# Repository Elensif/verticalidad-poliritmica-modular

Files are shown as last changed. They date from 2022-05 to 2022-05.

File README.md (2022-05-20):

# verticalidad-poliritmica-modular
Documentación del proyecto
Este proyecto corresponde a un trabajo perteneciente al segundo módulo del Taller de interacción, en dónde a partir de un trabajo previo de observación se diseño un tótem de 2mts. de altura con el cual una persona pueda interactuar. Los archivos de las siguientes carpetas corresponden a las piezas necesarias para armar el proyecto "Verticalidad polirítmica modular", dentro de ellas se podrán encontrar los documentos necesarios, descargables y editables para crear desde 0 el tótem.

Los autores de este proyecto son Nicolás Dragas, Daniela Sifaqui y Alejandra Witto, alumnos pertenecientes al Taller de interacción 2022 de la e[ad].
El registro del proyecto de inicio a fin se puede encontrar en el siguiente enlace: https://wiki.ead.pucv.cl/Verticalidad_polir%C3%ADtmica_modular

imagen

Dentro del repositorio existen 3 carpetas: cam, cad e ino. Dentro de la carpeta "cam" se encuentran los archivos de dibujo en formato "dwg" para descargar y editar, dentro de la carpeta "cad" se encuentran los modelos tridimensionales y en la carpeta "ino" se encuentra el código utilizado en arduino.

Los programas utilizados para realizar los archivos fueron: para los archivos DWG se utilizó autocad, para los modelos 3D se utilizó Iventor. Para cortar las piezas los archivos DWG se exportaron a .dxf y se cortarón en una láser. Para el registro gráfico se utilizaron render, inventor y cámaras de celular.

<br />Esta obra está bajo una <a rel="license" href="http://creativecommons.org/licenses/by-nc-sa/4.0/">Licencia Creative Commons Atribución-NoComercial-CompartirIgual 4.0 Internacional</a>.

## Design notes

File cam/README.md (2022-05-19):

Los siguientes archivos corresponden a todos los dibujos realizados en autocad para ser cortados en láser.

Los archivos: Piezas cajones gesto.dwg y Piezas cajones.dwg, corresponden a las piezas móviles del módulo. Para armar cada módulo se utilizó papel opalina blanco a de gramaje 200. Cada cajón cuenta con 1 pieza rectangular larga y dos pequeñas que van pegados a los costados. Cada pieza tiene viñetas las que se pegan entre si para tener bordes limpios en los cuerpos.
Los archivos ya se encuentran divididos en dos capas, una de corte y otra de grabado para realizar los plisados en el papel. Los parámetros utilizados para estos archivos fueron: 

Plisado (capa blanca)= Speed (mm/s): 500, sin repeticiones, Min Power(%) 15, Max Power(%) 15.

Corte (capa azul)= Speed (mm/s) 80, sin repeticiones, Min Power(%) 20, Max Power(%) 20.

Los archivos "Pieza separación interior.dwg", "Piezas interiores de cajones.dwg", "Piezas mecanismo carrito" corresponden a piezas que serán cortadas en MDF de 3mm de espesor. Los parámetros utilizados para estos archivos fueron:

Speed (mm/s) 30, sin repeticiones, Min Power(%) 70, Max Power(%) 70.

Los archivos "Dientes para cremallera.dwg" y "Engranaje presión para potenciometro.dwg", corresponden a las piezas que permiten el movimiento del potenciómerto del mecanismo eléctrico para hacer funcionar el sistema del tótem. 
Dentro del archivo "Dientes para cremallera.dwg" se encuentra un gran engranaje, para crear la cremallera según la extensión que se necesite se debe tomar un diente del engranaje e ir colocándolo uno al lado del otro hasta llegar a la longitud deseada, en el proyecto actual se hizo una pieza de 11cm x 2cm x 5mm, en donde a lo largo de los 11 centímetros va la cremallera.

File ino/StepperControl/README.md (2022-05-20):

El código que se encuentra en esta carpeta corresponde a uno utilizado en una placa arduino, para controlar la dirección y giro de un motor stepper con un potenciómetro.

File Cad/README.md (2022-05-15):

Los archivos que se encuentran de esta carpeta corresponden a los modelos 3D del tótem. Estos se realizaron con Inventor y se encuentran dibujados en escala 1:1.
Dentro de cada uno se puede ver el ensamblaje del proyecto, desde su estructura interna a externa.

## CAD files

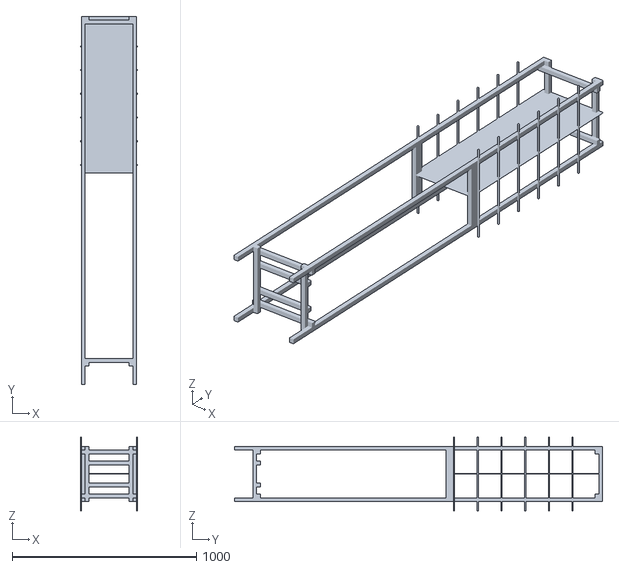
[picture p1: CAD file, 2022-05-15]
Cad/Esqueleto tótem.obj
312.0 x 2000.0 x 400.0

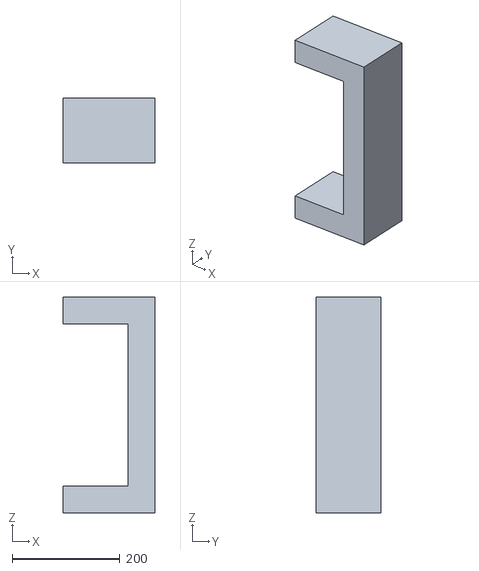
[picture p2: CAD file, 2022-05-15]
Cad/Cajón totem.obj
170.0 x 120.0 x 400.0

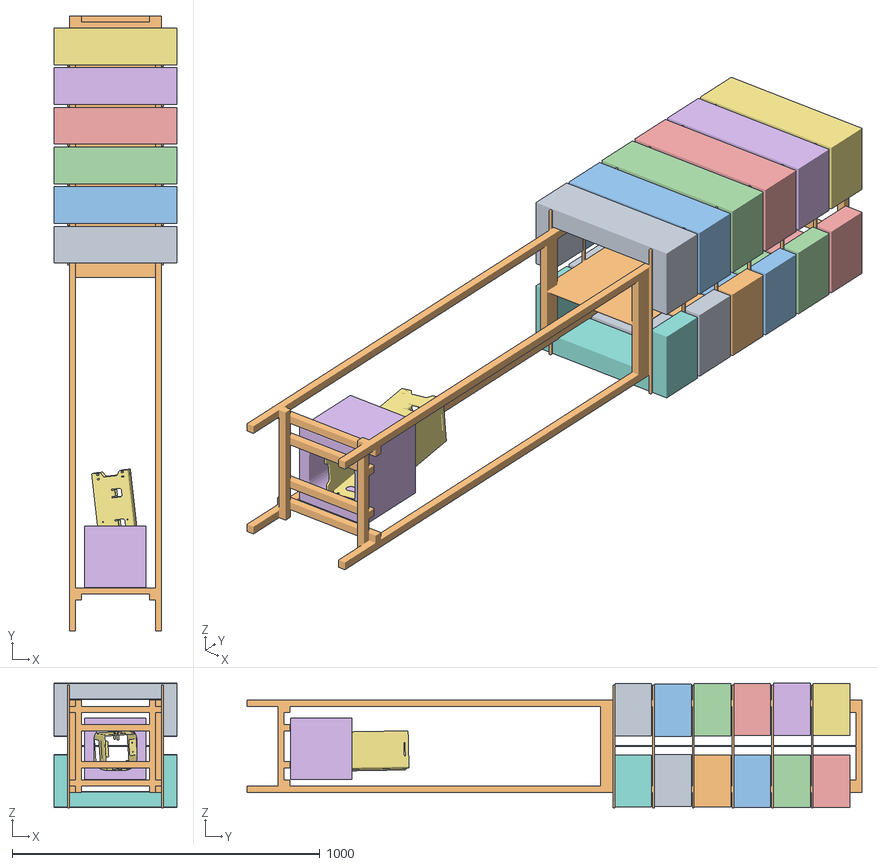
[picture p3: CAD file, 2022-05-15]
Cad/Verticalidad Poliritmica Modulada.obj
400.0 x 2000.0 x 404.9
Sólido1
Sólido1:1
Sólido1:2
Sólido1:3
Sólido1:4
Sólido1:5
Sólido1:6
Sólido1:7
Sólido1:8
Sólido1:9
Sólido1:10
Sólido1:11
Sólido1:12
Sólido1:13

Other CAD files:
cam/Pieza interior cajones mecanismo.dwg
cam/Dientes para cremallera.dwg
cam/Engranaje presión para potenciometro.dwg
cam/Piezas Mecanismo Carrito.dwg
cam/Pieza separación interior.dwg
cam/Piezas cajones gesto.dwg
cam/Piezas cajones.dwg

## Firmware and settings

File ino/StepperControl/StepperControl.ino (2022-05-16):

/*
 Stepper Motor Control - speed control

 This program drives a unipolar or bipolar stepper motor.
 The motor is attached to digital pins 8 - 11 of the Arduino.
 A potentiometer is connected to analog input 0.

 The motor will rotate in a clockwise direction. The higher the potentiometer value,
 the faster the motor speed. Because setSpeed() sets the delay between steps,
 you may notice the motor is less responsive to changes in the sensor value at
 low speeds.

 Created 30 Nov. 2009
 Modified 28 Oct 2010
 by Tom Igoe

 */

#include <Stepper.h>

const int stepsPerRevolution = 100;  // change this to fit the number of steps per revolution
// for your motor


// initialize the stepper library on pins 8 through 11:
Stepper myStepper(stepsPerRevolution, 8, 9, 10, 11);

int stepCount = 0;  // number of steps the motor has taken

void setup() {
  myStepper.setSpeed(500);
  Serial.begin(9600);
  // nothing to do inside the setup
}

void loop() {
  // read the sensor value:
  int sensorReading = analogRead(A0);
  // map it to a range from 0 to 100:
  int motorSpeed = map(sensorReading, 0, 1023, 0, 100);
  Serial.println(motorSpeed);

  if (motorSpeed < 45) {
    // step 1/100 of a revolution:
    myStepper.step(stepsPerRevolution);
    delay(20);
    
  } else if (motorSpeed > 55) {
    myStepper.step(-stepsPerRevolution);
    delay(20);
  } else {
    myStepper.step(0);
  }
}

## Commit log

2022-05-06 Create cad
2022-05-15 Add files via upload
    Archivos de corte láser realizados en autocad.
    [Piezas cajones gesto.dwg, Piezas cajones.dwg, Piezas interiores de cajones.dwg]
2022-05-15 Add files via upload
    Archivos de modelos 3D creados en inventor
    [Cajón totem.obj, Esqueleto tótem.obj, Verticalidad Poliritmica Modulada.obj]
2022-05-16 Código de uso Stepper
    Configuración del potenciometro
2022-05-19 Add files via upload
    Engranaje para potenciómetro metido a presión
    [Engranaje presión para potenciometro.dwg]
2022-05-19 Add files via upload
    Archivo creación de dientes para cremallera que va bajo el primer cajón en contacto con el engranaje
    [Dientes para cremallera.dwg]
